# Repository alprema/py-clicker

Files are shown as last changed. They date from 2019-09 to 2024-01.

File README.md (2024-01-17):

# py-clicker
Raspberry Pi score counter for Canne de combat

## Setup
**Version:** Rasbian Buster Lite

**Setup:**
* Configure Wifi connection / autologin in `raspi-config`
* Install the following packages:
  * adafruit-circuitpython-ssd1306 (pip)
  * python3-numpy (apt)
  * pigpio (http://abyz.me.uk/rpi/pigpio/download.html)
  * pyyaml (pip)
* Configure `clicker_config.yaml`
* Copy \*.py/\*.yaml to your home directory
* Add this line in `/etc/rc.local` before `exit 0`:
``` bash
    sudo pigpiod
```
* Add this line in /boot/config.txt
``` bash
    dtparam=i2c_arm_baudrate=1000000
```

* Configure WiFi in `/etc/wpa_supplicant/wpa_supplicant.conf `

* Add this to the end of your `.profile`:
``` bash
    # Run clicker.py only if not connected through SSH
    if [ -z "$SSH_CLIENT" ] || [ -z "$SSH_TTY" ]; then
        python3 /home/pi/py-clicker/clicker.py
    fi
```
* Reboot

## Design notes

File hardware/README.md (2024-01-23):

# Hardware

## Overview

[](clicker_front.jpg)
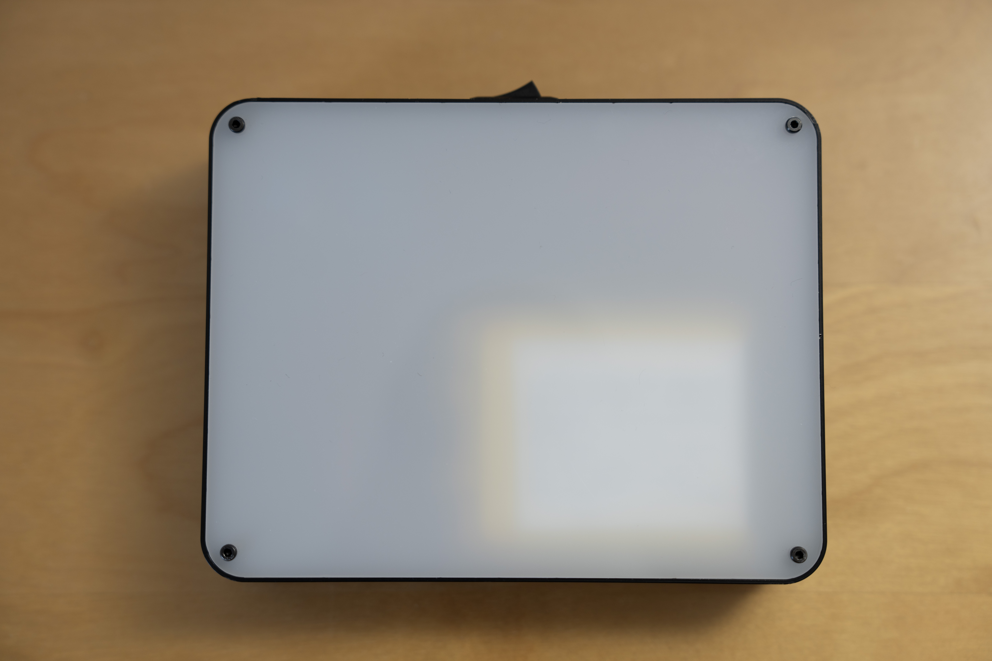
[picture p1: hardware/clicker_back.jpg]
[](clicker_back.jpg)
[](clicker_inside.jpg)

## Components
* 2 x AZDelivery SSD1306 OLED screen
* 1 x Raspberry Pi Zero W
* 1 x TP4056 battery charger
* 1 x MT3608 step up converter
* 1 x 5000MAh LiPo battery
* 3 x Clicker buttons
* 1 x Power button

## Pinout
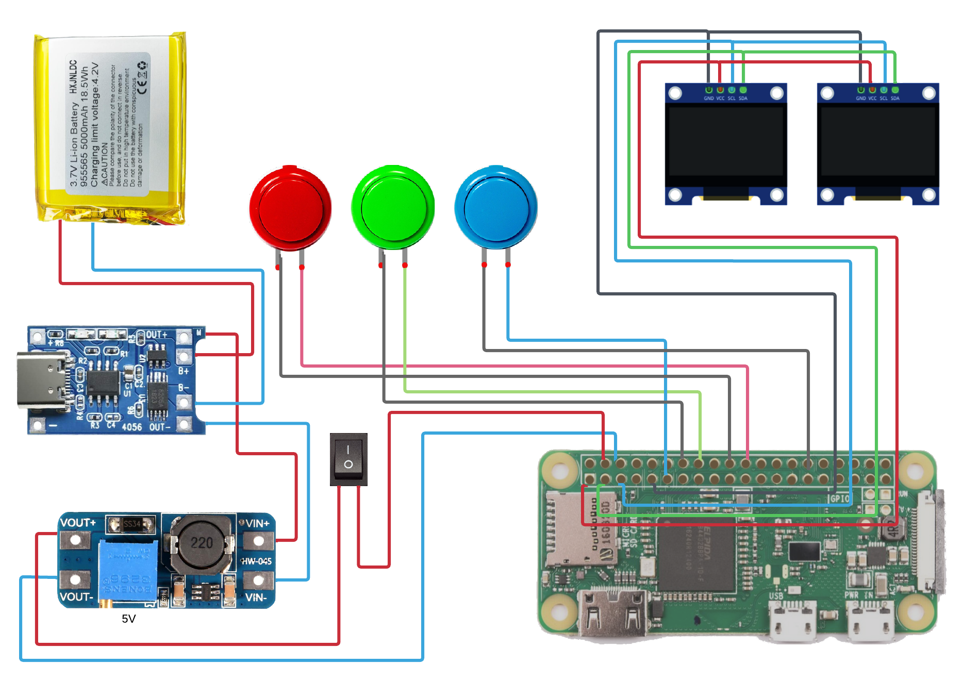
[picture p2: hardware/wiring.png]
Wiring

(Source: https://lucid.app/publicSegments/view/29dfcc4b-7ac9-45ab-b54a-e5f21a3d707d)

### Displays
- Left screen address: 0x3c
- Right screen address: 0x3d

### GPIO pinout
| Switch color | GPIO #|
|---|---|
| Red switch |25|
| Green switch (reset) |23|
| Blue switch |17|
| 5V+ input | 04 |
| 5V- input | 06 |
| Screen VCC+ | 01 |
| Screen VCC- | 09 |
| Screen SDA | 03 |
| Screen SCL | 05 |

## Casing
### Components
3D printed from `box_body.stl` using PLA for the casing. Machine cut from PMMA for the lid.

### Assembly
#### Cables
* Left screen: 4 x 5cm
* Right screen: 4 x 13 cm
* Red button: 2 x 12 cm
* Green button: 2 x 12 cm
* Blue button: 2 x 16 cm
* USB to step-up: 2 x 16 cm
* Step-up to RPI: 3 x 14 cm

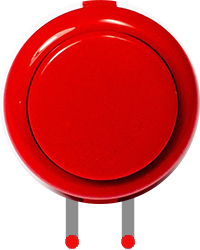
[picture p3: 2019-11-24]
hardware/red_button.png

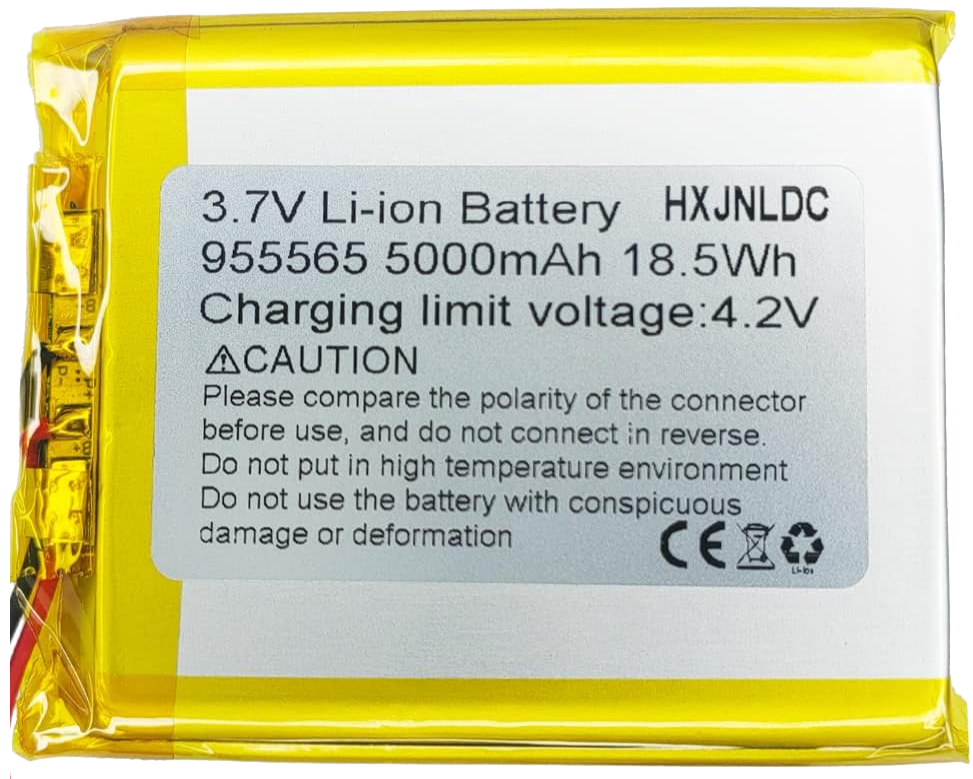
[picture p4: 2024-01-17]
hardware/battery.png

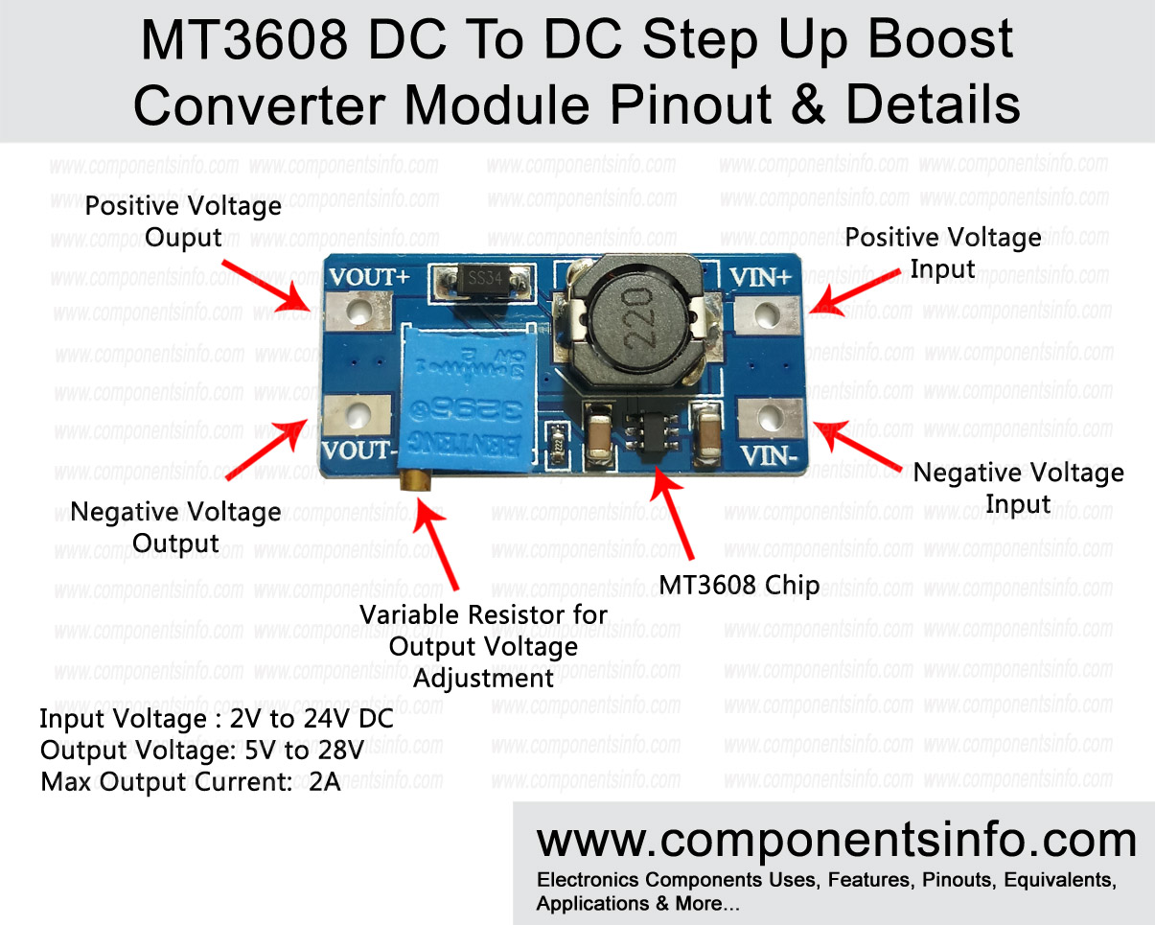
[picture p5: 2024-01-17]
hardware/mt3608-module-pinout-specs-3616079487.jpg

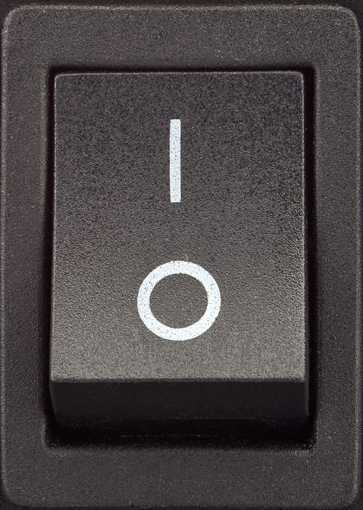
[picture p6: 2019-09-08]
hardware/power_switch.jpg

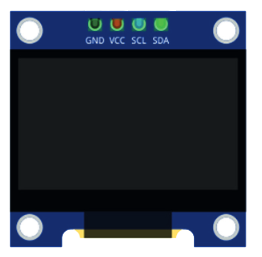
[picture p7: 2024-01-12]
hardware/ssd1306.png

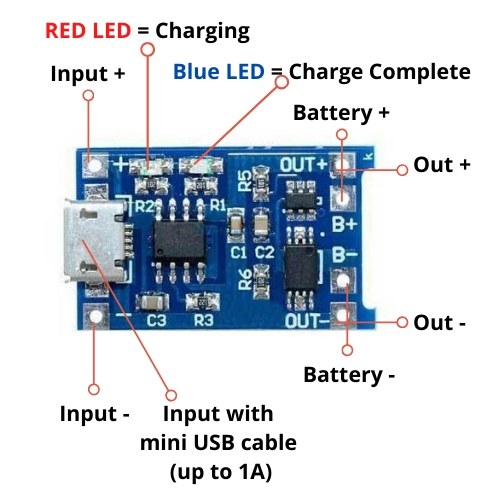
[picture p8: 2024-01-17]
hardware/TP4056-Charging-Module-Pinout-2562767375.jpg

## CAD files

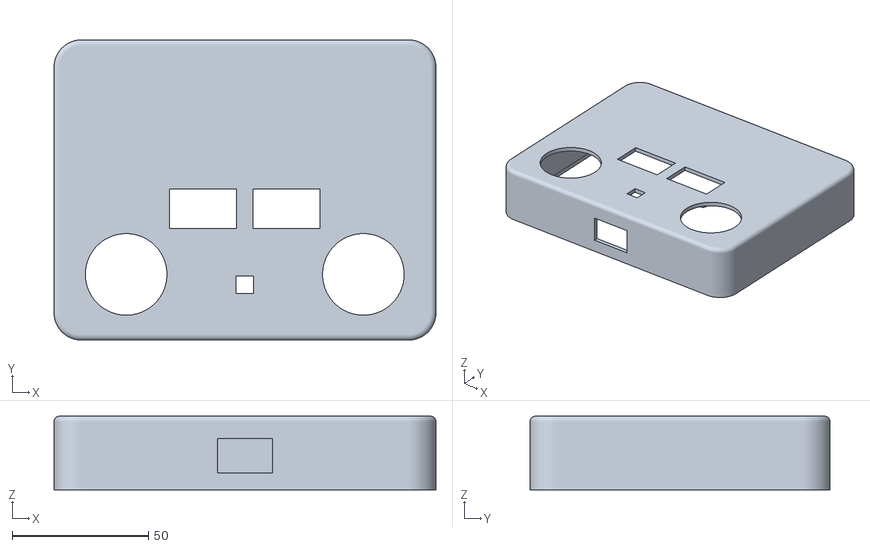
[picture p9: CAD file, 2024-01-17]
hardware/box_body.stl
140.0 x 110.0 x 27.0

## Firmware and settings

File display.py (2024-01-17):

import board
import os
import busio
from adafruit_ssd1306 import SSD1306_I2C
from typing import Optional
from enum import Enum

from adafruit_framebuf import BitmapFont


class Side(Enum):
    Left = 0
    Right = 1

class Display:
   
    def __init__(self):
        i2c = busio.I2C(board.SCL, board.SDA)
        self._left_screen: SSD1306_I2C = SSD1306_I2C(128, 64, i2c, addr=0x3c)
        self._left_screen.fill(0)
        self._left_screen.show()

        self._right_screen: SSD1306_I2C = SSD1306_I2C(128, 64, i2c, addr=0x3d)
        self._right_screen.fill(0)
        self._right_screen.show()

        self._ip = None
        self._previous_ip = None
        self._clicker_name = None
        self._previous_clicker_name = None
        self._red_score = 0
        self._previous_red_score = 0
        self._blue_score = 0
        self._previous_blue_score = 0

        self._width = self._left_screen.width
        self._height = self._left_screen.height

        self._font_location = os.path.join(os.path.dirname(__file__), "font5x8.bin")
        font = BitmapFont(self._font_location)
        self._font_base_width = font.font_width
        self._font_base_height = font.font_height



    def _print_score(self, screen: SSD1306_I2C, score: int, color: int):
        score_string_size = 5
        digits = 1 if score < 10 else 2

        string_width = digits * self._font_base_width * score_string_size + ((digits - 1) * score_string_size)
        string_height = self._font_base_height * score_string_size

        screen.text(
            str(score),
            self._width // 2 - string_width // 2,
            self._height // 2 - string_height // 2,
            color,
            font_name=self._font_location,
            size=score_string_size
        )
    
    def _print_bottom_line(self, screen: SSD1306_I2C, text: Optional[str], color: int):
        if text is None:
            return

        bottom_string_size = 1
        digits = len(text)

        string_width = digits * self._font_base_width * bottom_string_size + ((digits - 1) * bottom_string_size)
        string_height = self._font_base_height * bottom_string_size

        screen.text(
            text,
            self._width - string_width,
            self._height - string_height,
            color,
            font_name=self._font_location,
            size=bottom_string_size
        )


    def _update_score(self, side: Side):
        if side == Side.Left:
            previous_score = self._previous_red_score
            score = self._red_score
            screen = self._left_screen
            self._previous_red_score = self._red_score
        else:
            previous_score = self._previous_blue_score
            score = self._blue_score
            screen = self._right_screen
            self._previous_blue_score = self._blue_score
        

        # Display the previous score in black before the current score in white,
        # thus clearing it by sending as few pixels as possible to the screen (faster)
        self._print_score(screen, previous_score, color=0)
        self._print_score(screen, score, color=1)
        
        screen.show()


    def _update_bottom_line(self, side: Side):
        if side == Side.Left:
            previous_bottom_line = self._previous_clicker_name
            bottom_line = self._clicker_name
            screen = self._left_screen
            self._previous_clicker_name = self._clicker_name
        else:
            previous_bottom_line = self._previous_ip
            bottom_line = self._ip
            screen = self._right_screen
            self._previous_ip = self._ip

           
        self._print_bottom_line(screen, previous_bottom_line, color=0)
        self._print_bottom_line(screen, bottom_line, color=1)      


    def set_ip(self, ip: Optional[str]):
        self._ip = ip
        self._update_bottom_line(Side.Right)

    def set_clicker_name(self, clicker_name: str):
        self._clicker_name = clicker_name
        self._update_bottom_line(Side.Left)

    def set_red_score(self, score: int):
        self._red_score = score
        self._update_score(Side.Left)


    def set_blue_score(self, score: int):
        self._blue_score = score
        self._update_score(Side.Right)

     
    def shutdown(self):
        self._left_screen.fill(0)
        self._left_screen.show()

        self._right_screen.fill(0)
        self._right_screen.show()

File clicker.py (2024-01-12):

import os
import pigpio
import requests
import yaml
import json
import asyncio
from datetime import datetime
from timeit import default_timer as timer
from enum import Enum
from display import Display

RED = 'Red'
BLUE = 'Blue'

class PressType(Enum):
    long_press="long_press"
    short_press="short_press"

config_file_path = os.path.join(os.path.dirname(os.path.realpath(__file__)), "clicker_config.yaml")

with open(config_file_path, 'r') as stream:
    try:
        configuration = yaml.safe_load(stream)
    except yaml.YAMLError as exc:
        print(exc)
        exit(1)

print('Configured with identifier: ' + configuration['clicker-identifier'])

first_click_made = False
pi = pigpio.pi()
display = Display()
loop = asyncio.get_event_loop()
scores = { RED: 0, BLUE: 0 }
api_call_count = 0
log_file = open(f"clicker_log_{datetime.now().strftime('%Y-%m-%d_%H-%M-%S')}", "w+")

def call_api(button: int, press_type: PressType):
    global api_call_count
    api_call_count += 1
    data = {
        "serial": configuration['clicker-identifier'],
        "buttonId": button,
        "typeClick": press_type.value,
        "internalState": {
            "0": api_call_count,
            "1": scores[RED],
            "2": scores[BLUE]
        }
    }
    
    requests.post(configuration['outgoing-url'], data=json.dumps(data), headers={"Content-Type": "application/json", "X-Requested-With":"XMLHttpRequest"})

def button_pressed(tick, color):
    global first_click_made
    # Ignoring presses in the first 100 ms to avoid ghost clicks
    # but using first_click_made to prevent ignoring clicks after wraparound every 71.6 minutes
    if not first_click_made and tick - startup_tick < 100 * 1000: 
        return
    
    first_click_made = True
    
    scores[color] += 1
    
    if color == RED:
        display.set_red_score(scores[RED])
    else:
        display.set_blue_score(scores[BLUE])

    print('Button pressed (%s), calling URL' % color)
    log_file.write(f"{datetime.now().strftime('%Y-%m-%d_%H-%M-%S.%f')}  Blue: {scores[BLUE]} Red: {scores[RED]}\n")
    log_file.flush()
    loop.call_soon_threadsafe(lambda _: call_api(1 if color == RED else 2, PressType.short_press), '')


_last_reset_press_tick = pi.get_current_tick()

def reset_pressed(gpio, level, tick):
    global _last_reset_press_tick
    if level == 0:
        _last_reset_press_tick = tick
        pi.set_watchdog(gpio, 1000)
        return
    
    pi.set_watchdog(gpio, 0)
    
    if level == 2:
        pressed_time_micros = pigpio.tickDiff(_last_reset_press_tick, tick)
        if pressed_time_micros < 1000 * 1000:
            return
        print('RESET PRESSED')
        scores[RED] = 0
        scores[BLUE] = 0
        update_score()
        loop.call_soon_threadsafe(lambda _: call_api(0, PressType.long_press), '')

def update_score():
    display.set_red_score(scores[RED])
    display.set_blue_score(scores[BLUE])

def _setup_switch(pin: int, callback, edge=pigpio.FALLING_EDGE):
    pi.set_mode(pin, pigpio.INPUT)
    pi.set_pull_up_down(pin, pigpio.PUD_UP)
    pi.set_glitch_filter(pin, 20 * 1000) # Time in µs
    pi.callback(pin, edge, callback)

try:
    import socket
    hostname = socket.gethostname()
    ip = socket.gethostbyname(f'{hostname}.local')
    print(f"IP: {ip}")

    display.set_ip(ip)
    display.set_clicker_name(configuration['clicker-identifier'].split("_")[0])
    display.set_red_score(0)
    display.set_blue_score(0)
    
       
    startup_tick = pi.get_current_tick()
    _setup_switch(25, lambda gpio, level, tick: button_pressed(tick, RED))
    _setup_switch(17, lambda gpio, level, tick: button_pressed(tick, BLUE))
    _setup_switch(23, reset_pressed, edge=pigpio.EITHER_EDGE)

    loop.run_forever()
except KeyboardInterrupt:
    print("Exiting")
    log_file.close()
    loop.close()

display.shutdown()
pi.stop()

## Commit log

2019-08-15 Initial import
    Current state:
    - Display score on 7-segment display
    - Support reset
    - Call remote API on button press
    [clicker.py]
2019-08-17 Add LED display documentation
2019-08-17 Switch to pigpio library
2019-08-24 Replace tabs with four spaces
    [clicker.py]
2019-08-25 Change GPIO pins to new prototype mapping
2019-11-24 Allow for scrolling display
    Show the IP at startup thanks to scrolling display + add a startup
    safety interval to prevent ghost clicks.
    [clicker.py, display.py]
2019-11-24 Add wiring diagram
2019-11-24 Add image of the wiring in readme.md
2020-01-08 Add a flag to monitor first clicker
    The mechanism to prevent ghost clicks during the first 100ms could
    prevent clicks from being registered after the ticks wrap around every
    71.6 minutes.
    [clicker.py]
2020-01-08 Update assembly instructions
2024-01-17 Update wiring with new components
    [box_body.stl]
2024-01-17 Replace buck converter with step up converter
2024-01-17 Add wiring sizes
2024-01-23 Add printing information.
